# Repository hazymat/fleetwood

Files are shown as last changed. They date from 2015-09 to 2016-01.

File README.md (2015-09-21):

# fleetwood
Home Automation Room Controller

*** NOTE: Support for this project is not possible, however collaborators are warmly encouraged to contact me! ***

Project consists of:
- Arduino Sketch intended for Arduino Mega 2560
- Eagle files for 4 PC boards

1/ Sketch and Eagle schematics and board layouts are shared for information only.
2/ This project does not yet include an official BOM.

   Copyright 2015 Mat Smith

   Licensed under the Apache License, Version 2.0 (the "License");
   you may not use this file except in compliance with the License.
   You may obtain a copy of the License at

       http://www.apache.org/licenses/LICENSE-2.0

   Unless required by applicable law or agreed to in writing, software
   distributed under the License is distributed on an "AS IS" BASIS,
   WITHOUT WARRANTIES OR CONDITIONS OF ANY KIND, either express or implied.
   See the License for the specific language governing permissions and
   limitations under the License.

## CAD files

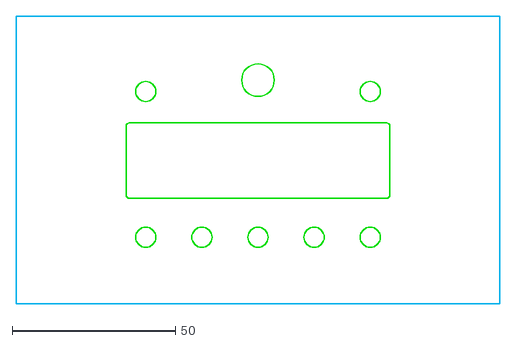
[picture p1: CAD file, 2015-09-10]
Eagle/Upper-Board/frontplate-with-outline-V4.dxf
148.1 x 88.1

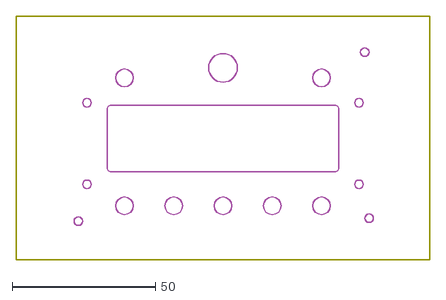
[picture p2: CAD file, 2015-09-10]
Eagle/Upper-Board/rearplate-with-outline-V4.dxf
144.3 x 85.0

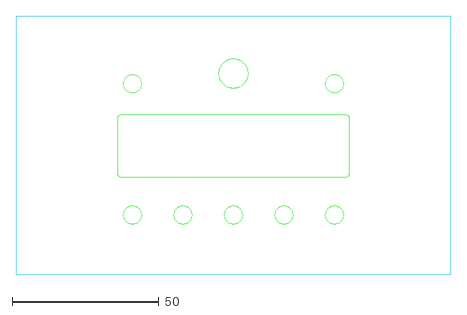
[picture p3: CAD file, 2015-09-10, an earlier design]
Eagle/Upper-Board/frontplate-with-outline-V2.dxf
148.1 x 88.1

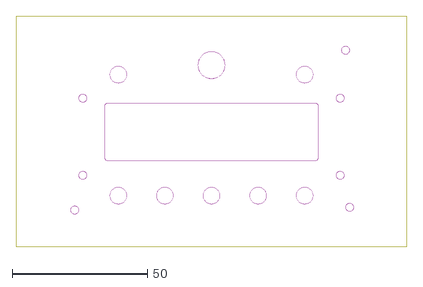
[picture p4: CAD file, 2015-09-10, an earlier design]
Eagle/Upper-Board/rearplate-with-outline-V3.dxf
144.3 x 85.0

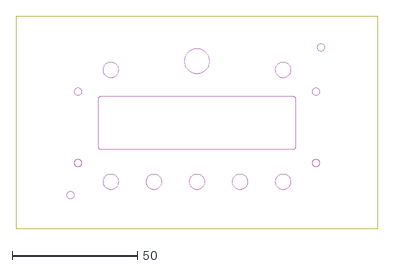
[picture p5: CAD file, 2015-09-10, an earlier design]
Eagle/Upper-Board/rearplate-with-outline-V2.dxf
144.3 x 85.0

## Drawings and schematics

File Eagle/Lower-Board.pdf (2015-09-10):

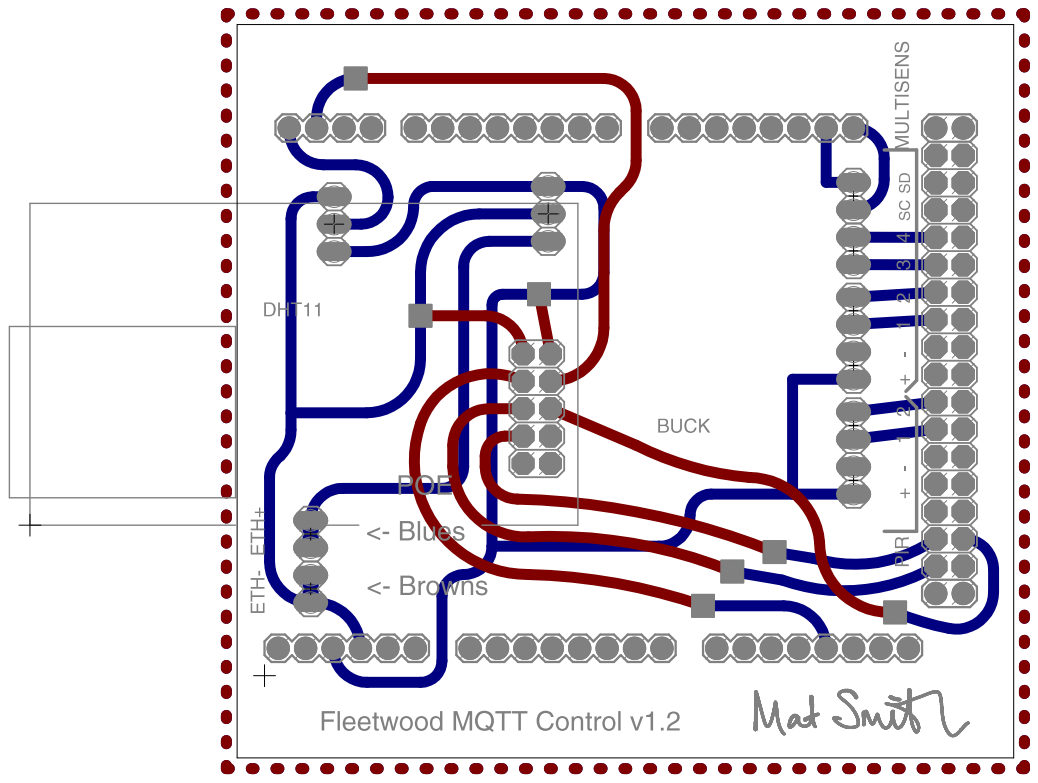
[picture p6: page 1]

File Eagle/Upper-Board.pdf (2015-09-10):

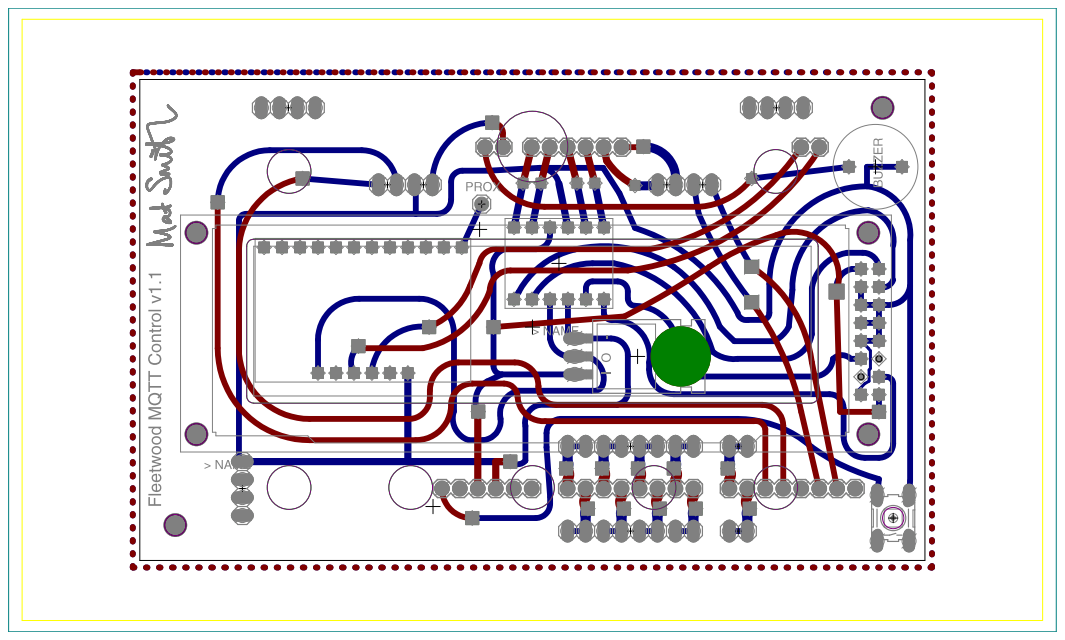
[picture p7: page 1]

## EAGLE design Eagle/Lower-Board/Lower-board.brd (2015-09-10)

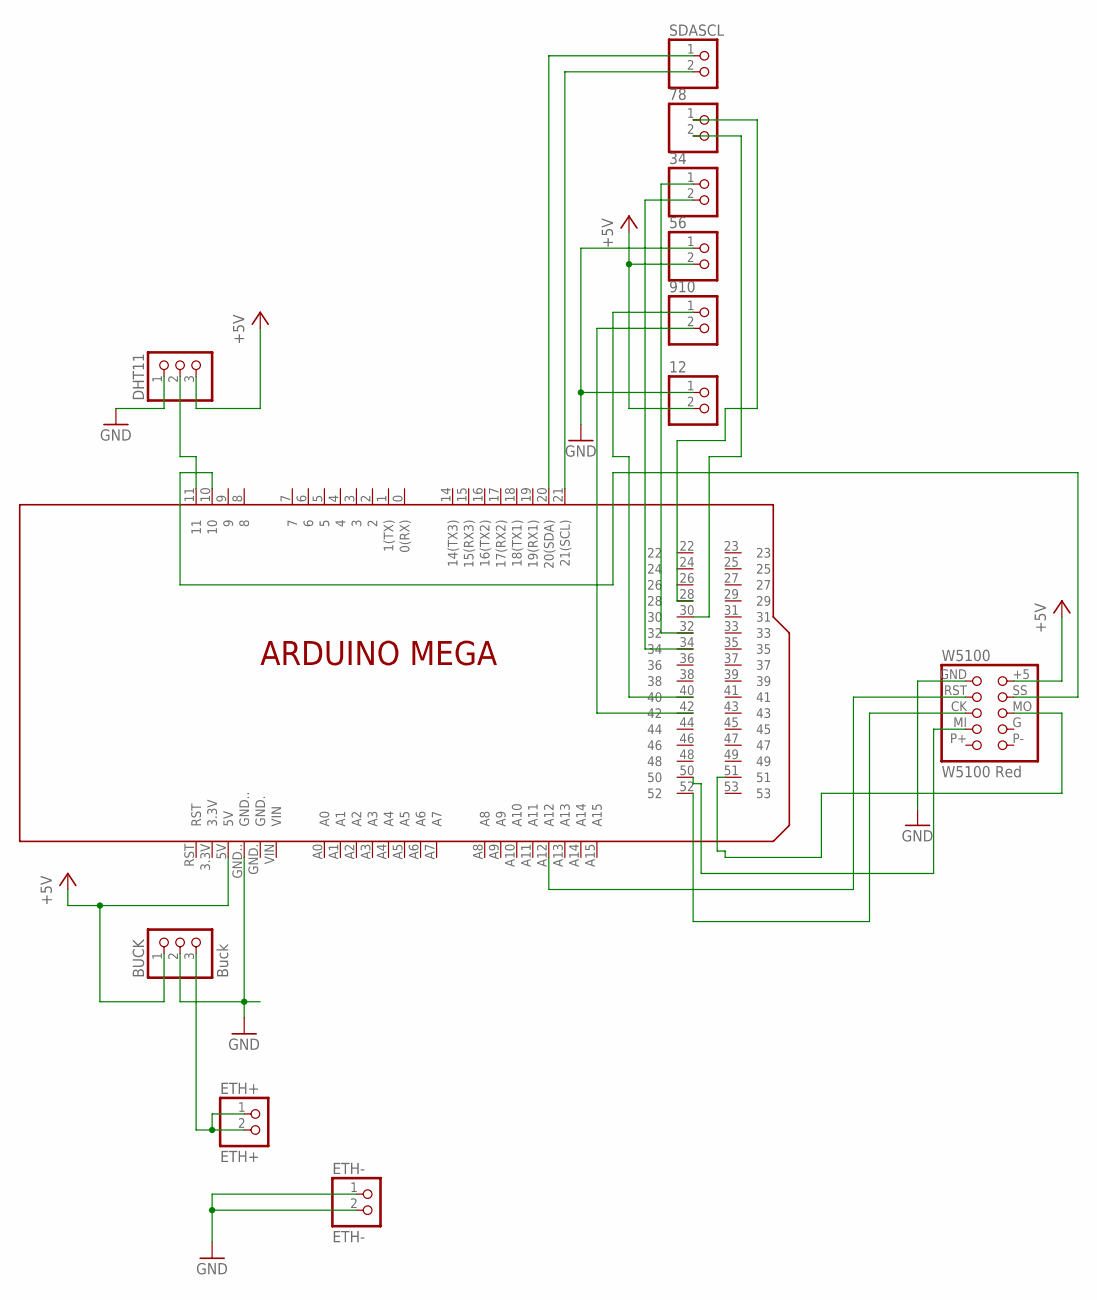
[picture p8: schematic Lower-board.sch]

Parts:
12, 34, 56, 78, 910: PINHD-1X2; 1X02
BUCK: Buck; 1X03
DHT11: PINHD-1X3; 1X03
ETH+: ETH+; 1X02
ETH-: ETH-; 1X02
SDASCL: PINHD-1X2; 1X02
U$1: ARDUINO_MEGA_1
W5100: W5100 Red; W5100-RED

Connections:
+5V: 12.2, 56.2, BUCK.1, DHT11.3, U$1.5V, W5100.+5
GND: 12.1, 56.1, BUCK.2, DHT11.1, ETH-.1, ETH-.2, U$1.GND.., W5100.GND
unnamed: BUCK.3, ETH+.1, ETH+.2
unnamed: SDASCL.2, U$1.21 (21(SCL))
unnamed: SDASCL.1, U$1.20 (20(SDA))
unnamed: DHT11.2, U$1.11
unnamed: 910.2, U$1.42
unnamed: 910.1, U$1.40
unnamed: 34.2, U$1.34
unnamed: 34.1, U$1.32
unnamed: 78.1, U$1.28
unnamed: 78.2, U$1.30
unnamed: U$1.52, W5100.CK
unnamed: U$1.50, W5100.MI
unnamed: U$1.A12, W5100.RST
unnamed: U$1.10, W5100.SS
unnamed: U$1.51, W5100.MO

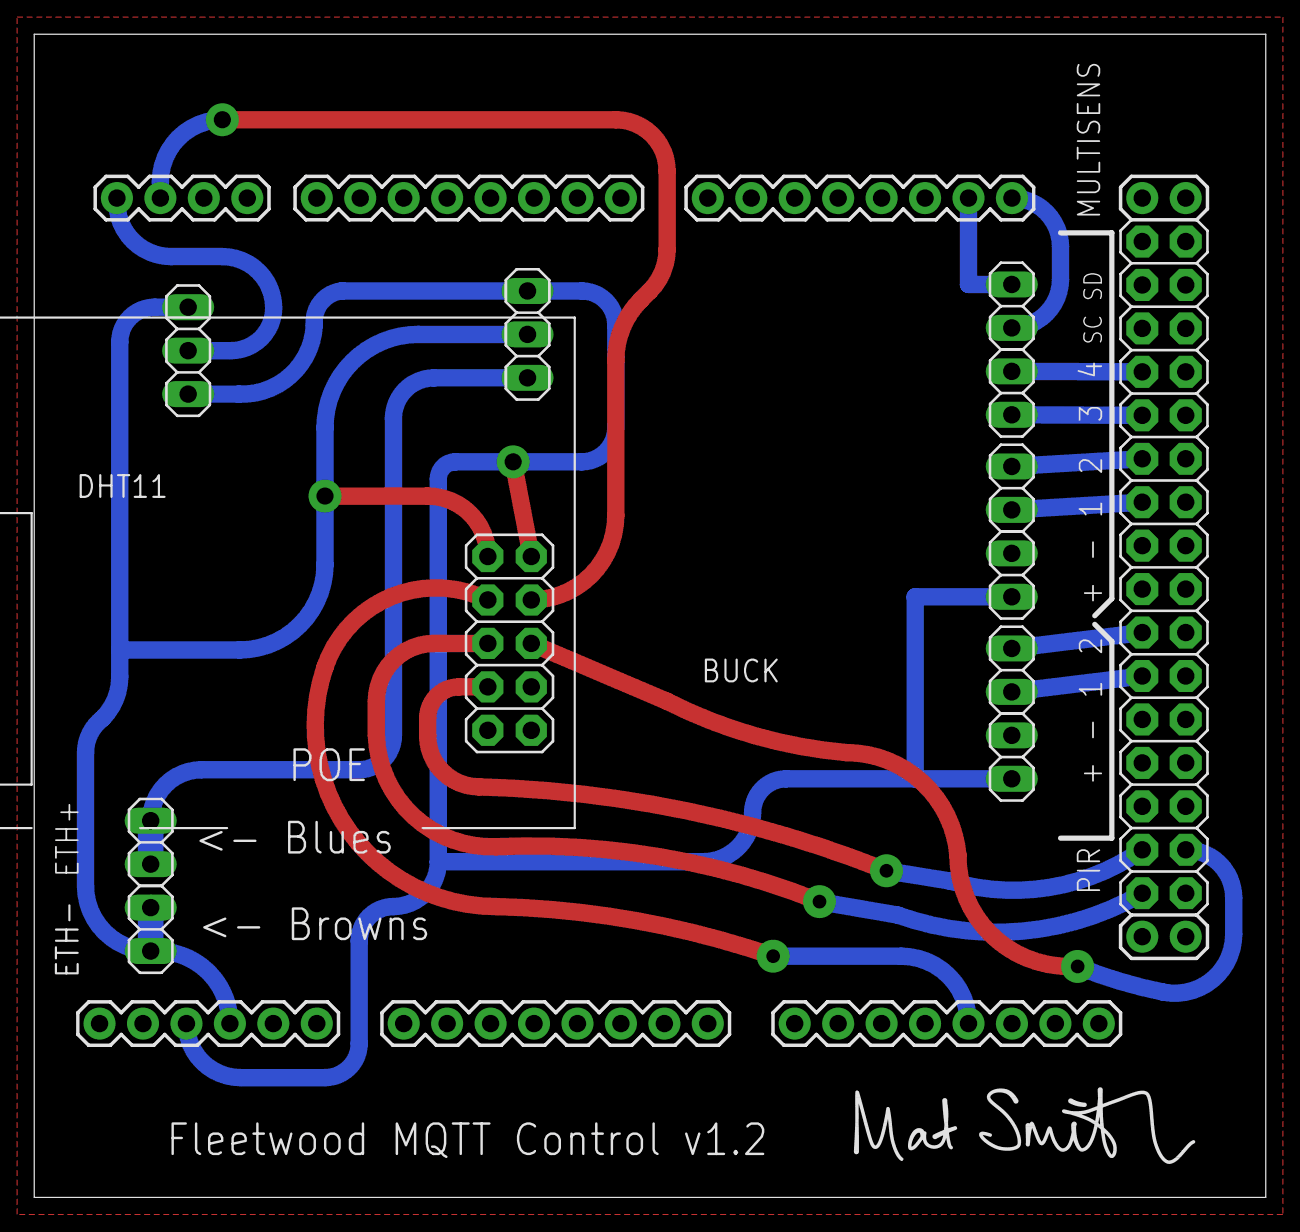
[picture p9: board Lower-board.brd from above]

Board: 2 copper layers, 72.0 x 68.0 mm, 12 parts (0 on the bottom side), 17 nets.

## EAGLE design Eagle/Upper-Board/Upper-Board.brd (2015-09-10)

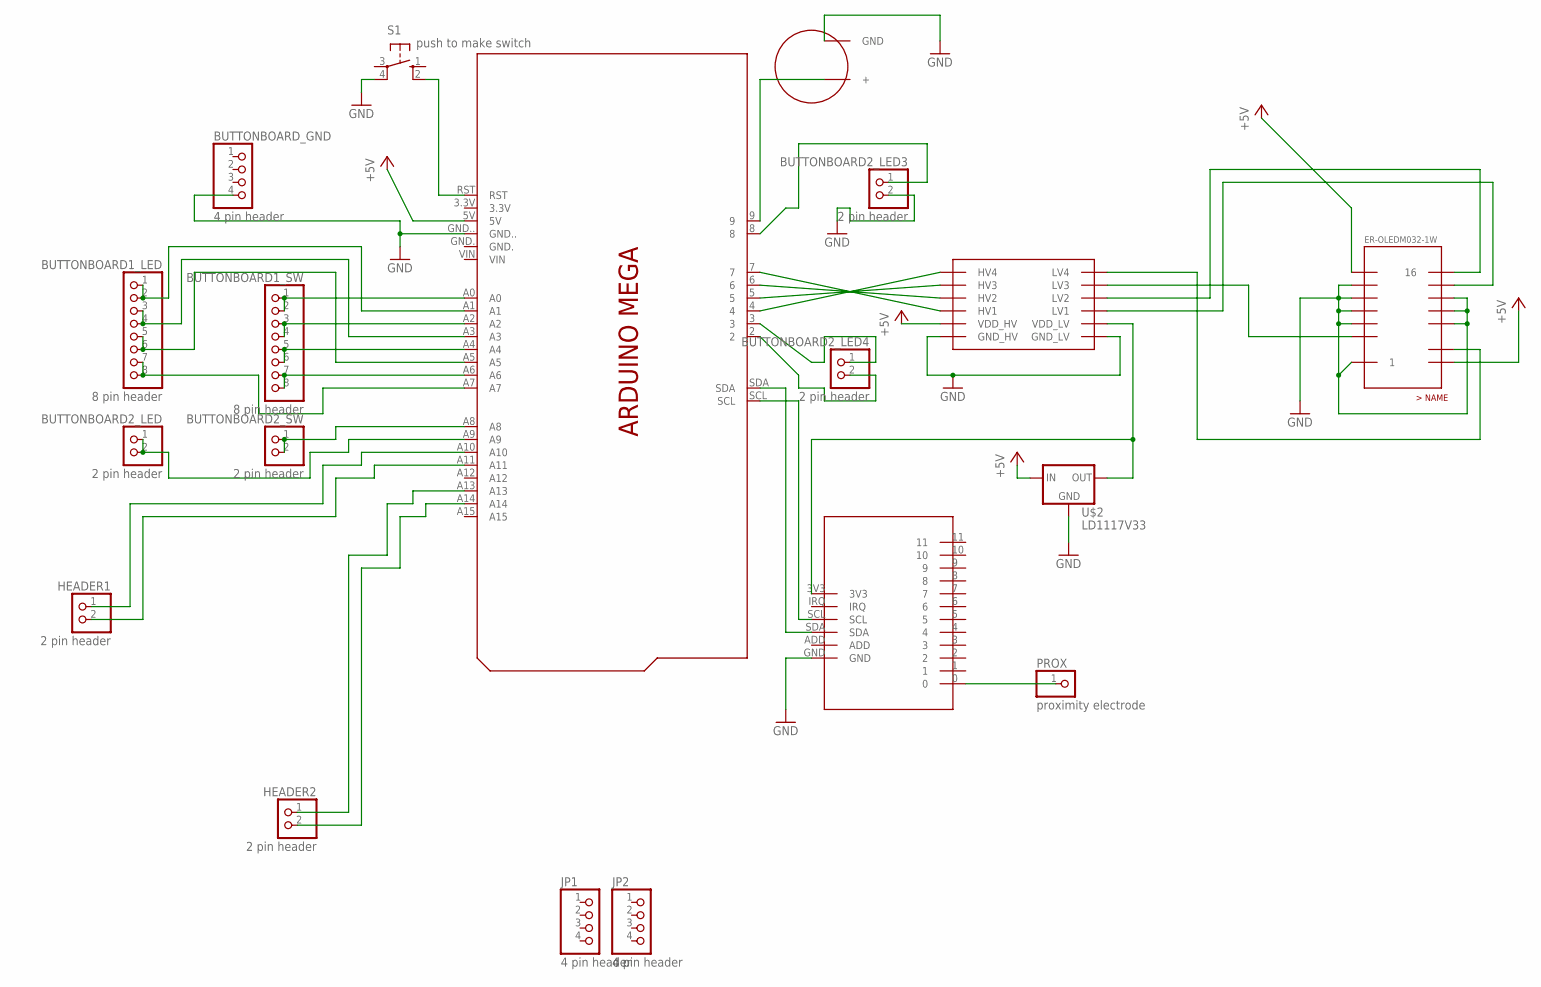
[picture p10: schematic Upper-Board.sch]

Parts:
BUTTONBOARD1_LED, BUTTONBOARD1_SW: 8 pin header; 1X08
BUTTONBOARD2_LED, BUTTONBOARD2_LED3, BUTTONBOARD2_LED4, BUTTONBOARD2_SW: 2 pin header; 1X02
BUTTONBOARD_GND: 4 pin header; 1X04
HEADER1, HEADER2: 2 pin header; 1X02
JP1, JP2: 4 pin header; 1X04
PROX: proximity electrode; 1X01
S1: push to make switch; B3F-10XX
U$1: ARDUINO_MEGA_2
U$2: LD1117V33
U$3: ER-OLED-M032-1W
U$4: BI_DIRECTIONAL_LEVEL_CONV
U$5: MPR121_BREAKOUT
U$6: BUZZER

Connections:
+5V: U$1.5V, U$2.IN, U$3.2, U$3.15, U$4.VDD_HV
GND: BUTTONBOARD2_LED3.2, BUTTONBOARD_GND.4, S1.4 (P1), U$1.GND.., U$2.GND, U$3.1, U$3.7, U$3.8, U$3.9, U$3.10, U$3.11, U$3.12, U$3.13, U$4.GND_HV, U$4.GND_LV, U$5.GND, U$6.GND
unnamed: BUTTONBOARD1_SW.1, BUTTONBOARD1_SW.2, U$1.A0
unnamed: BUTTONBOARD1_SW.3, BUTTONBOARD1_SW.4, U$1.A2
unnamed: BUTTONBOARD1_SW.5, BUTTONBOARD1_SW.6, U$1.A4
unnamed: BUTTONBOARD1_SW.7, BUTTONBOARD1_SW.8, U$1.A6
unnamed: BUTTONBOARD2_SW.1, BUTTONBOARD2_SW.2, U$1.A8
unnamed: BUTTONBOARD1_LED.1, BUTTONBOARD1_LED.2, U$1.A1
unnamed: U$1.SDA, U$5.SDA
unnamed: BUTTONBOARD1_LED.3, BUTTONBOARD1_LED.4, U$1.A3
unnamed: BUTTONBOARD1_LED.5, BUTTONBOARD1_LED.6, U$1.A5
unnamed: BUTTONBOARD1_LED.7, BUTTONBOARD1_LED.8, U$1.A7
unnamed: S1.2 (S1), U$1.RST
unnamed: BUTTONBOARD2_LED.1, BUTTONBOARD2_LED.2, U$1.A9
unnamed: U$1.SCL, U$5.SCL
unnamed: PROX.1, U$5.0
unnamed: U$1.9, U$6.+
unnamed: BUTTONBOARD2_LED3.1, U$1.8
unnamed: BUTTONBOARD2_LED4.1, U$1.3
unnamed: BUTTONBOARD2_LED4.2, U$1.2
unnamed: U$1.4, U$4.HV4
unnamed: U$1.5, U$4.HV3
unnamed: U$1.6, U$4.HV2
unnamed: U$1.7, U$4.HV1
unnamed: U$2.OUT, U$4.VDD_LV, U$5.3V3
unnamed: U$3.14, U$4.LV1
unnamed: U$3.16, U$4.LV2
unnamed: U$3.5, U$4.LV3
unnamed: U$3.4, U$4.LV4
unnamed: HEADER2.1, U$1.A13
unnamed: HEADER2.2, U$1.A14
unnamed: HEADER1.1, U$1.A10
unnamed: HEADER1.2, U$1.A11

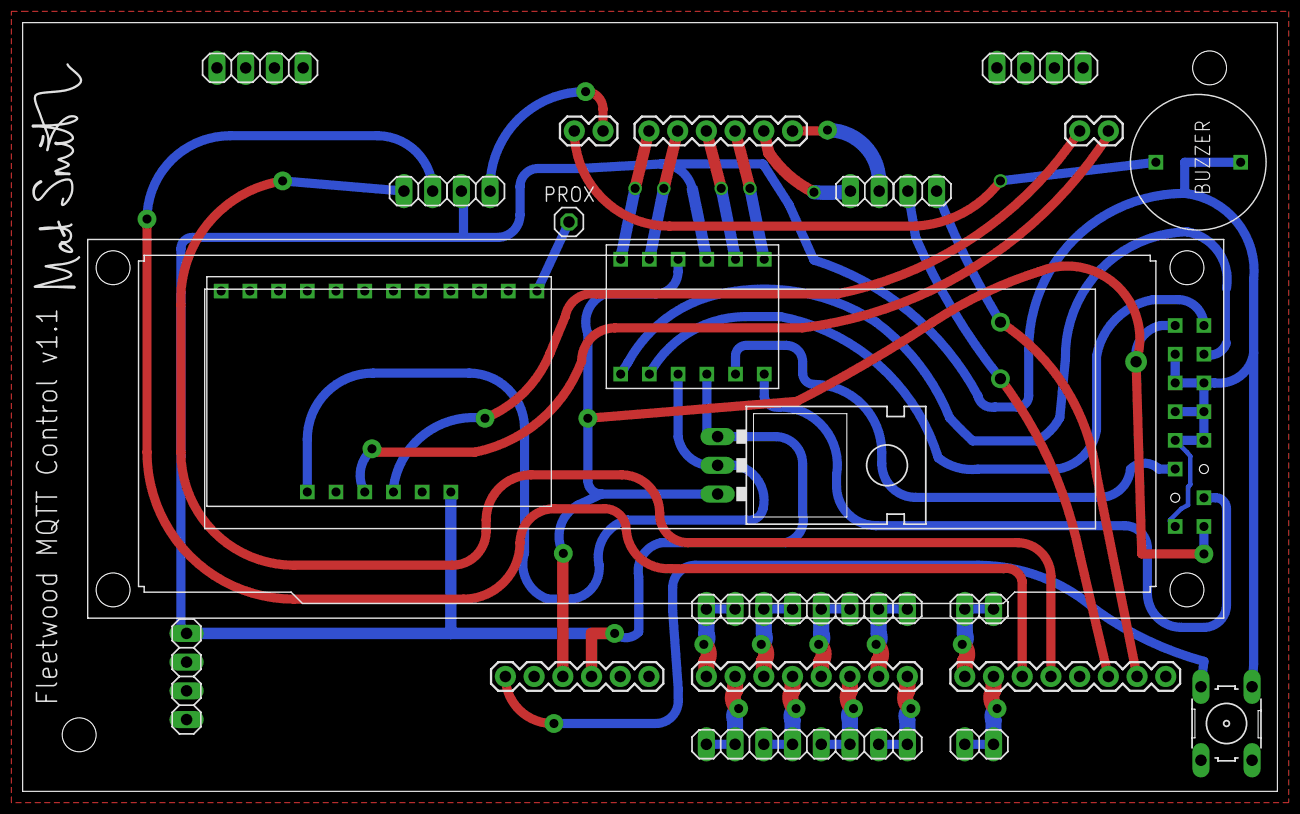
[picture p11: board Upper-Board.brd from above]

Board: 2 copper layers, 111.0 x 68.0 mm, 19 parts (0 on the bottom side), 33 nets.

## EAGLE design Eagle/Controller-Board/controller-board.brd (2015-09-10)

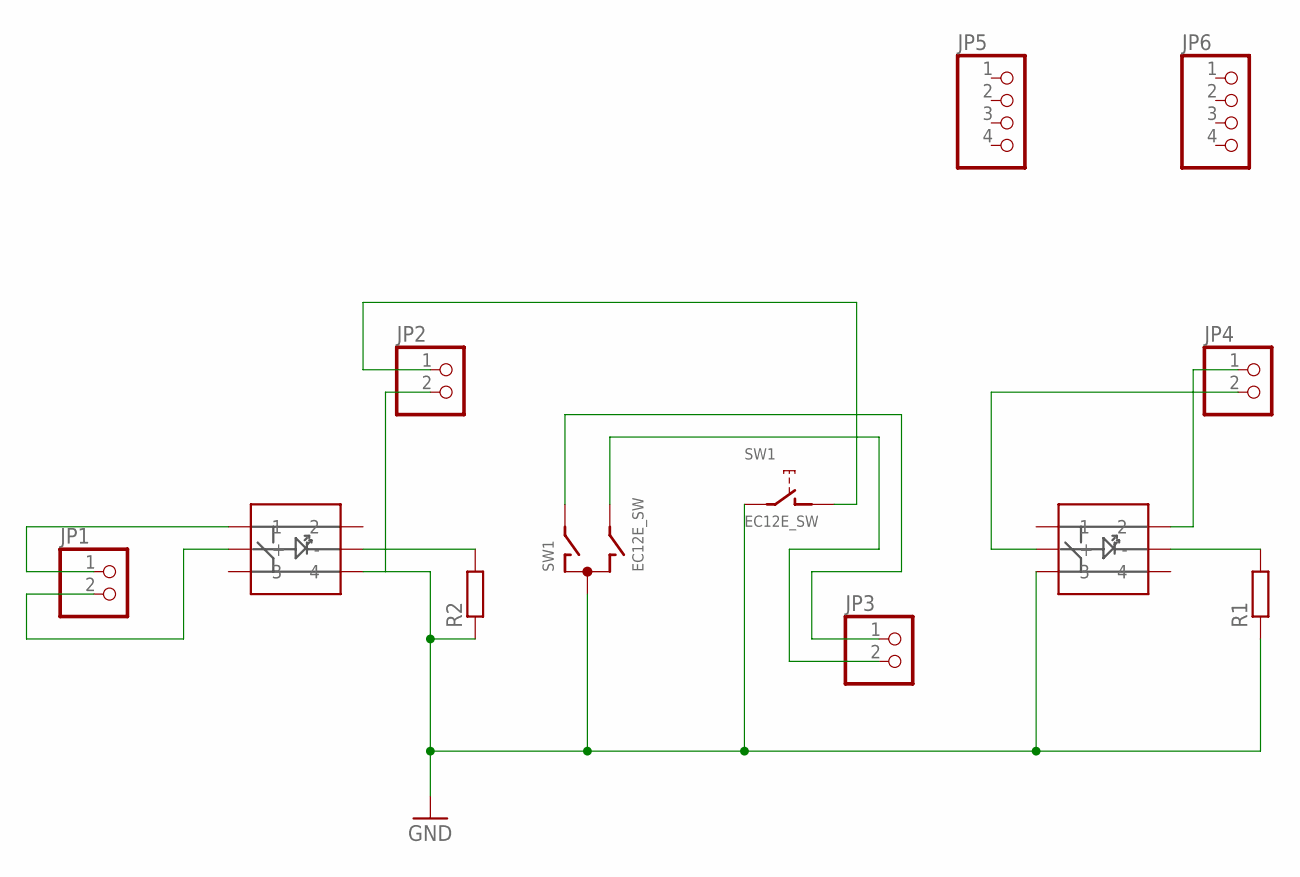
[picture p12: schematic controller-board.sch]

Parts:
BTN_MODE: PB614
BTN_OFF: PB614
JP1, JP2, JP3, JP4: PINHD-1X2; 1X02
JP5, JP6: PINHD-1X4; 1X04
R1, R2: R-EU_R1206; R1206
SW1: EC12E_SW; ALPS_EC12E_SW

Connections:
GND: BTN_MODE.4, BTN_OFF.3, JP2.2, R1.1, R2.1, SW1.C, SW1.E (2)
LED_MODE: BTN_MODE.L+ (+), JP1.2
unnamed: BTN_MODE.L- (-), R2.2
unnamed: BTN_OFF.L- (-), R1.2
unnamed: JP2.1, SW1.D (1)
unnamed: JP3.2, SW1.B
unnamed: JP3.1, SW1.A
unnamed: BTN_OFF.L+ (+), JP4.2
unnamed: BTN_OFF.2, JP4.1
SW_MODE: BTN_MODE.1, JP1.1

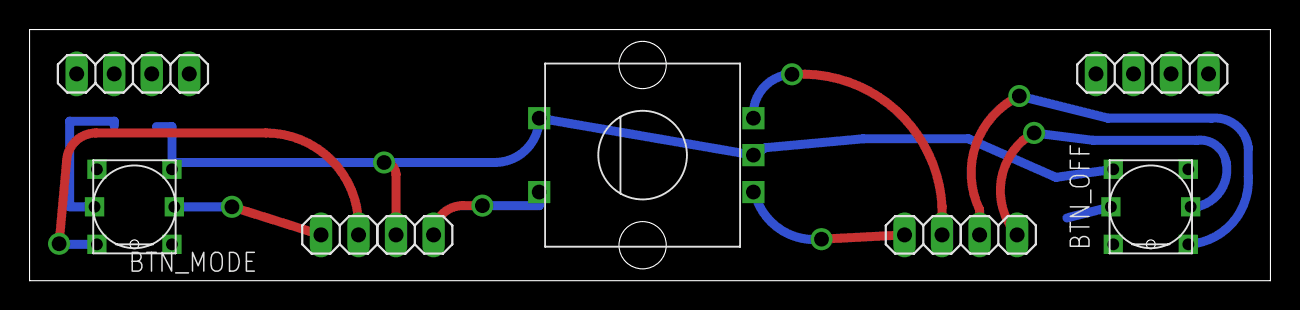
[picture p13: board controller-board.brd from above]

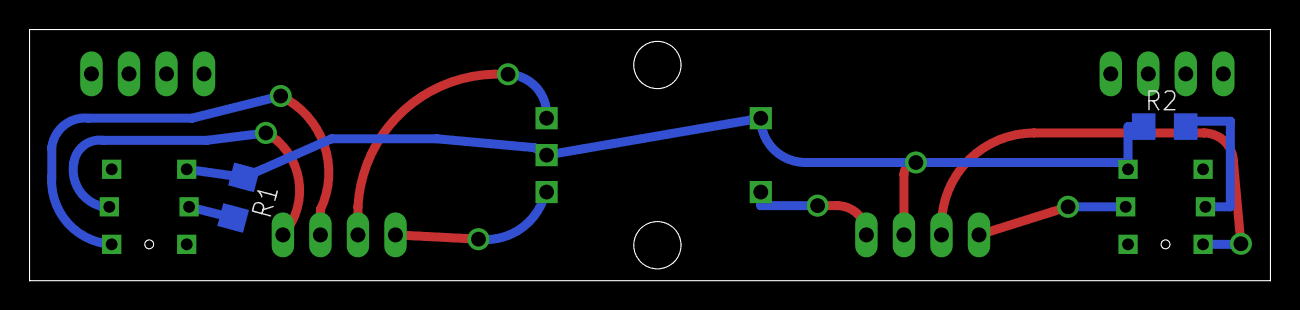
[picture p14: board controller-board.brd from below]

Board: 2 copper layers, 84.0 x 17.0 mm, 11 parts (2 on the bottom side), 10 nets.

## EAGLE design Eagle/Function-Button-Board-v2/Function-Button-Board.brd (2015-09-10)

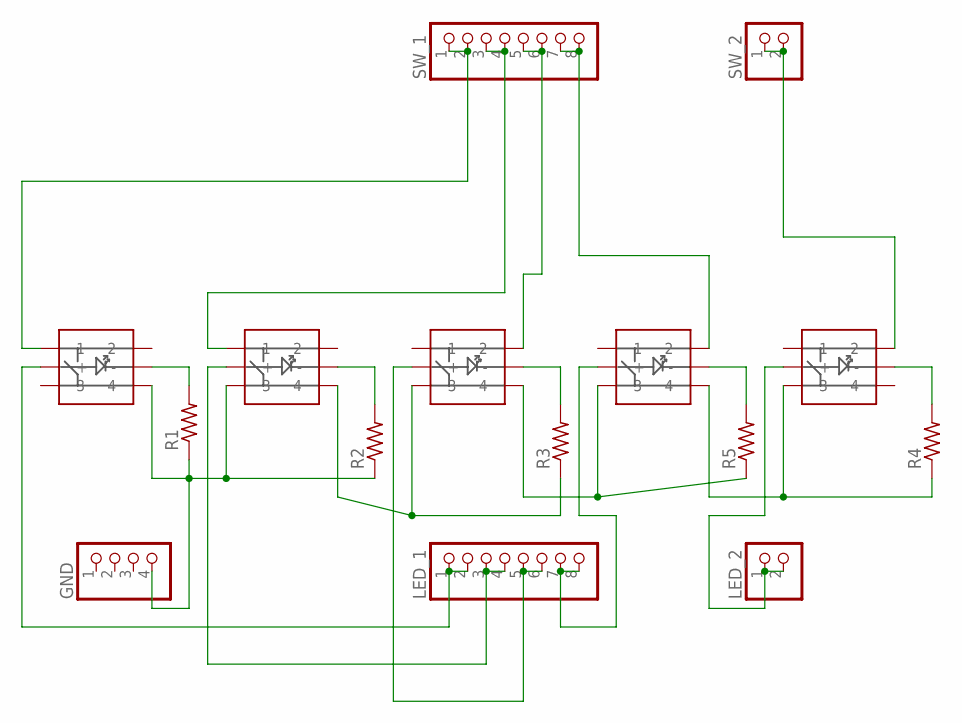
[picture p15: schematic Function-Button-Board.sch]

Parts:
FN_1, FN_2, FN_3, FN_4, FN_5: PB614
GND: PINHD-1X4; 1X04
LED_1: PINHD-1X8; 1X08
LED_2: PINHD-1X2; 1X02
R1, R2, R3, R4, R5: R-US_R1206; R1206
SW_1: PINHD-1X8; 1X08
SW_2: PINHD-1X2; 1X02

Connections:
unnamed: FN_1.L+ (+), LED_1.1, LED_1.2
unnamed: FN_1.L- (-), R1.2
unnamed: FN_1.1, SW_1.1, SW_1.2
unnamed: FN_3.L+ (+), LED_1.5, LED_1.6
unnamed: FN_1.4, FN_2.3, GND.4, R1.1, R2.1
unnamed: FN_4.L+ (+), LED_1.7, LED_1.8
unnamed: FN_2.1, SW_1.3, SW_1.4
unnamed: FN_2.L+ (+), LED_1.3, LED_1.4
unnamed: FN_5.L+ (+), LED_2.1, LED_2.2
unnamed: FN_2.L- (-), R2.2
unnamed: FN_3.L- (-), R3.2
unnamed: FN_2.4, FN_3.3, R3.1
unnamed: FN_4.L- (-), R5.2
unnamed: FN_5.L- (-), R4.2
unnamed: FN_3.2, SW_1.5, SW_1.6
unnamed: FN_3.4, FN_4.3, R5.1
unnamed: FN_5.2, SW_2.1, SW_2.2
unnamed: FN_4.2, SW_1.7, SW_1.8
unnamed: FN_4.4, FN_5.3, R4.1

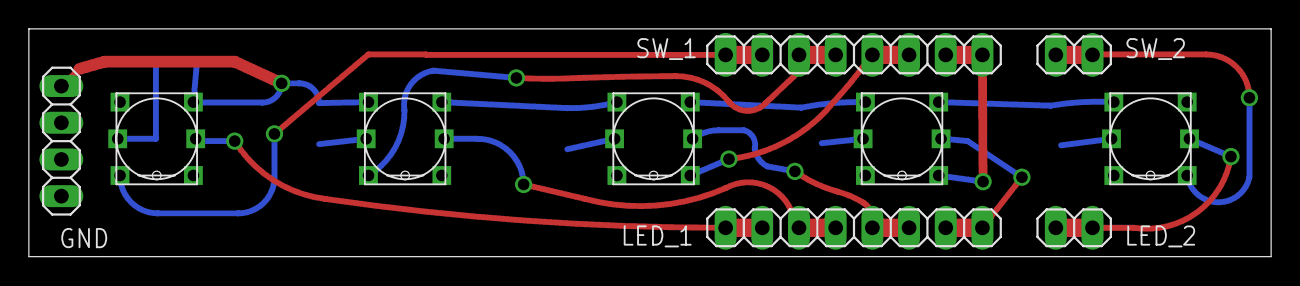
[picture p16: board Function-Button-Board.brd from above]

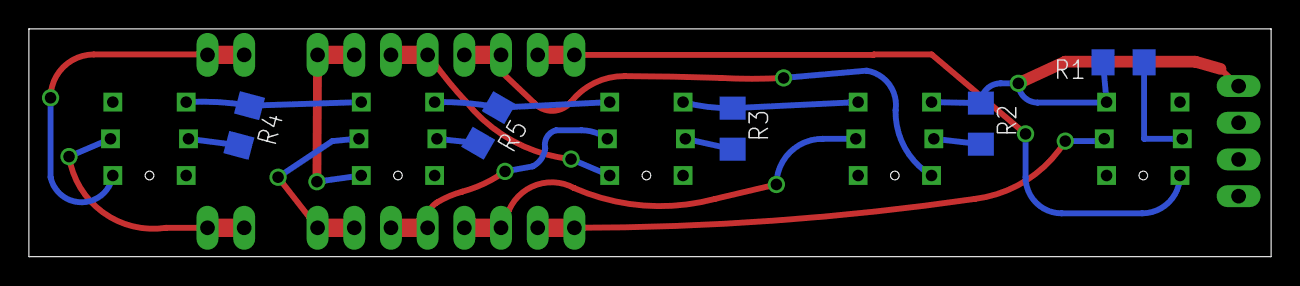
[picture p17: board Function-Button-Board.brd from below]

Board: 2 copper layers, 86.0 x 15.8 mm, 15 parts (5 on the bottom side), 19 nets.

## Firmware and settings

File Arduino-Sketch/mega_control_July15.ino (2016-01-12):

// 10/01/2016
/******************************************/
/*           Unit Settings                */
/******************************************/
// This unit's MAC address. MAC address is used for OpenHAB to recognise this controller at startup
// and give it the settings it should have, e.g. zone assignment, etc.
// i.e. zero config!
byte mac[] = {0xDE, 0xED, 0xBA, 0xFE, 0xFE, 0xED};  


/******************************************/
/*           Server settings              */
/******************************************/
// MQTT Server IP Address
byte server[] = {192, 168, 0, 21};

/******************************************/
/*           Display settings             */
/******************************************/
// Is the remote multisensor connected, i.e. do we wish to display lux setting?
#define showlightlevel 0

/******************************************/
/*           MQTT Topic Naming            */
/******************************************/
// MQTT topic naming. We are sending commands over MQTT topics like this:
//   rootvector/zonevector/commandvector
//   e.g. home/bedroom/arduinocommands
// ALL commands are sent on this one topic, however values received back over MQTT are
//   received over multiple topics.
// NB The zonevector is determined at startup by "downloading" this from OpenHAB over MQTT.
//   meaning that OpenHAB will determine the assigned zone given this unit's MAC address.
//   This makes it quick to deploy lots of units, as you'd only need to change the MAC above.
// None of the below really need changing! They are 'internal' names. Change only if you want different names for topics.
//   Topic paths are built from the below names.
#define rootvector "home"                          // do not exceed 10 chars, see below sram note
#define commandvector "megacmd"                    // do not exceed 10 chars, see below sram note
#define setupvector "megasetup"                    // do not exceed 10 chars
#define datetimevector "datetime/arduinodisplay"   // hmmm, think about #sram later. This seems ok
#define audiovector "audio"
#define titlevector "title"
#define artistvector "artist"
#define tempvector "temp"
#define boilervector "boiler"
#define weathervector "weath"
#define settempvector "settemp"
#define currentvector "current" // 
#define volumevector "volume" // 
#define playstatusvector "playstatus" // 
#define settingsvector "settings" // 
#define circuitcountvector "circuit_count" // 
#define circuit_1_namevector "circuit_1_name" // NB don't enter actual circuit names here. This is the vector used to obtain circuit names
#define circuit_2_namevector "circuit_2_name" // NB don't enter actual circuit names here. This is the vector used to obtain circuit names
#define circuit_3_namevector "circuit_3_name" // NB don't enter actual circuit names here. This is the vector used to obtain circuit names
#define circuit_4_namevector "circuit_4_name" // NB don't enter actual circuit names here. This is the vector used to obtain circuit names
#define circuit_5_namevector "circuit_5_name" // NB don't enter actual circuit names here. This is the vector used to obtain circuit names
#define circuit_6_namevector "circuit_6_name" // NB don't enter actual circuit names here. This is the vector used to obtain circuit names
#define light_scene_1_namevector "light_scene_1_name" // NB don't enter actual light scene names here...
#define light_scene_2_namevector "light_scene_2_name" // NB don't enter actual light scene names here...
#define light_scene_3_namevector "light_scene_3_name" // NB don't enter actual light scene names here...
#define light_scene_4_namevector "light_scene_4_name" // NB don't enter actual light scene names here...
#define light_scene_5_namevector "light_scene_5_name" // NB don't enter actual light scene names here...
#define audio_fave_1_namevector "audio_fave_1_name" // NB don't enter actual audio fave names here...
#define audio_fave_2_namevector "audio_fave_2_name" // NB don't enter actual audio fave names here...
#define audio_fave_3_namevector "audio_fave_3_name" // NB don't enter actual audio fave names here...
#define audio_fave_4_namevector "audio_fave_4_name" // NB don't enter actual audio fave names here...
#define audio_fave_5_namevector "audio_fave_5_name" // NB don't enter actual audio fave names here...
#define lightvector "light" //
#define circuit1levelvector "circuit1level" //
#define circuit2levelvector "circuit2level" //
#define circuit3levelvector "circuit3level" //
#define circuit4levelvector "circuit4level" //
#define circuit5levelvector "circuit5level" //
#define circuit6levelvector "circuit6level" //
#define heat_fave_1_namevector "heating_fave_1_name" // NB don't enter actual audio fave names here...
#define heat_fave_2_namevector "heating_fave_2_name" // NB don't enter actual audio fave names here...
#define heat_fave_3_namevector "heating_fave_3_name" // NB don't enter actual audio fave names here...
#define heat_fave_4_namevector "heating_fave_4_name" // NB don't enter actual audio fave names here...
#define heat_fave_5_namevector "heating_fave_5_name" // NB don't enter actual audio fave names here...


/******************************************/
/*          SRAM management note         */
/******************************************/
// I have hashtagged possible areas for improvement / troubleshooting regarding SRAM. So if we see
//   problems such as random text on screen then search for #sram.
// Most likely culprit would be buff[43]. To my calculations, assuming a topic root of
//   no more than 10 chars plus null terminator, buff[43] should be safe!
// Light circuit names, scene names, and audio favourites should be 11 chars max. This could be increased
//   by changing the struct 

/******************************************/
/*          Include libraries             */
/******************************************/

#include <ClickButton.h>
#include <Encoder.h>
#include <SPI.h>
#include <Ethernet.h>
#include <PubSubClient.h>
#include "U8glib.h"
#include "DHT.h" // DHT11/22 temp / humidity
#include <Wire.h>
#include <BH1750.h>            // #lux
#include "Adafruit_MPR121.h"   // #prox


/******************************************/
/*               Defines                  */
/******************************************/

// #sram memory management
// Maximum length for strings. This is the actual number of chars, we account for null terminator
//   on top of this. Keep this as LOW as poss.
#define nameLength 11      // Light circuit, scene, and audio fave names. (suggest 12)
#define trackLength 30     // Now Playing track: max length to accept / display onto Arduino. (suggest 60)
#define artistLength 32    // Now Playing artist: as above. (suggest 60)

// comment below line out if not debugging
#define DEBUG      // code step-through

// Pins
#define btn1Pin 		54	// illuminated tact switch - Switch part
#define led1Pin 		55	// illuminated tact switch - LED
#define btn2Pin 		56	// illuminated tact switch - Switch part
#define led2Pin 		57	// illuminated tact switch - LED
#define btn3Pin 		58	// illuminated tact switch - Switch part
#define led3Pin 		59	// illuminated tact switch - LED
#define btn4Pin 		60	// illuminated tact switch - Switch part
#define led4Pin 		61	// illuminated tact switch - LED
#define btn5Pin 		62	// illuminated tact switch - Switch part
#define led5Pin 		63	// illuminated tact switch - LED
#define btnMode 		64	// illuminated tact switch - Switch part
#define ledMode 		65	// illuminated tact switch - LED
#define btnAllOff               67
#define ledAllOff               68
#define encoder1 		3	// rotary encoder - right hand pin in row of 3 as you look down
#define encoder2 		2	// rotary encoder - left hand pin in row of 3 as you look down
#define encodersw 		8	// rotary encoder - switch part
#define oledClock		4	// OLED
#define oledData		5	// OLED
#define chipSelect		6	// OLED
#define commandDataSelect	7	// OLED
#define resetCtl                66      // don't ask. (separate w5100 reset)
#define ardReset                69      // hardwired to reset pin of Arduino - physical reset by MQTT
#define DHTPIN                  32      // was pin 11. With latest version of PCB, this is an external connector


//BREADBOARD:
/*
#define btnMode 		54	// illuminated tact switch - Switch part
#define ledMode 		55	// illuminated tact switch - LED
#define btn1Pin 		56	// illuminated tact switch - Switch part
#define led1Pin 		57	// illuminated tact switch - LED
#define btn2Pin 		58	// illuminated tact switch - Switch part
#define led2Pin 		59	// illuminated tact switch - LED
#define btn3Pin 		60	// illuminated tact switch - Switch part
#define led3Pin 		61	// illuminated tact switch - LED
#define btn4Pin 		62	// illuminated tact switch - Switch part
#define led4Pin 		63	// illuminated tact switch - LED
#define btn5Pin 		64	// illuminated tact switch - Switch part
#define led5Pin 		65	// illuminated tact switch - LED
#define encoder1 		2	// rotary encoder - right hand pin in row of 3 as you look down
#define encoder2 		3	// rotary encoder - left hand pin in row of 3 as you look down
#define encodersw 		8	// rotary encoder - switch part
#define oledClock		4	// OLED
#define oledData		5	// OLED
#define chipSelect		6	// OLED
#define commandDataSelect	7	// OLED
#define resetCtl                66      // don't ask. (separate w5100 reset)
#define ardReset                69      // hardwired to reset pin of Arduino - physical reset by MQTT
#define DHTPIN                  11      // DHT11 sensor (DHT22 is better, I had stock of the 11...)
*/

// Modes
#define lightMode 1
#define audioMode 2
#define tempMode 3
#define weatherMode 4
#define mvhrMode 5
#define otherMode 6
#define diagsMode 7
#define settingsMode 8

#define modeCount 7      // This is the number of modes to cycle through. There are other "hidden" modes, settings / diags.

// Proximity sense. We're calibrating this manually, using output from Serial Monitor to show us continuous values...
// Set baseline to lowest value you read from Serial Monitor (when no hand is near sensor)
// Set initial threshold to the number which, when capacitance goes below this number, the "touch" is sensed and controller wakes up etc.
// This initial threshold simply sets a value which can subsequently be overwritten by OpenHAB if we want to adjust this later
// 14/5/2015 - 656. Had to wait a good minute.

#define capBaseline 656                // Lowest value for Mat's wallplates is 670 #prox
#define capInitialThreshold 5          // Decent safety margin #prox

// Timeouts
#define w5100resetdelay 800            // Definitely safe: 1500. Probably ok 500?
#define startuphold 0                  // How long should we delay startup so allow us to view
                                       //   the final page of status messages? (set to 0 for now as added big delays to settings request routine)
                                       //   ... i.e. no point in delaying even more at startup
#define button_leds_off_timeout 5000
#define default_mode_timeout 913500
#define display_dim_timeout 97000
#define display_off_timeout 919000
#define heartbeat_timeout 61000 // we expect an MQTT message at least every 60 seconds
#define initialmqttconnecttimeout 5000 // should be 35000
#define preset_stored_msg_timeout 1500


// Delay between requesting each setting / value over MQTT to allow OH to process
// On this front, Arduino is really reliable with fast processing of MQTT, OpenHAB is not so!
#define mqttsettingsreqdelay 400
#define mqttvalreqdelay 400

#define DHTTYPE DHT22   // DHT 22
#define dhtpolldelay 20000    // Take reading and send every e.g. 20 seconds
#define lightSensorDelay 1000 // #lux
#define scrollwait 1000 // time to wait before scrolling text

/******************************************/
/*            Define settings             */
/******************************************/

// #sram memory hungry this struct is! mainly because of the char text[30]
struct serverData
{
  char name[nameLength+1];    // for storing a name of the server setting (e.g. "Ceiling")
  int level;                  // for storing a numerical value for the setting if applicable (e.g. 30)
//  char text[30];            // for storing a text value for the setting if applicable (e.g. audio track name)
  int gotName;                // (e.g. if the name was downloaded successfully, this is set to 1)
  int gotLevel;               // (e.g. if a settingTextVal OR settingNumberVal was downloaded successfully, this is set to 1)
};

struct weather {
  char name[nameLength+1];
  char min[4];
  char max[4];
  char precip[4];
  char conditiontext[25];
  char humid[4];
};

typedef struct serverData ServerData;
typedef struct weather Weather;

Weather weatherDay[5];

ServerData lightCircuit[6];  // store circuit names and light levels for 6 light circuits in a room
ServerData lightScene[5];
ServerData audioFave[5];
ServerData heatingProfile[5];

// server values
boolean play_status;
char track[trackLength+1];
char artist[artistLength+1];
char serverdatetime[17];
int temp; // #sram We aren't this desperate, but if we were, this could be stored as a char or byte
int volume; // #sram
int temp_target; // #sram
int mvhr_speed; // #sram
char zonename[15] = {'<','d','e','f','a','u','l','t','>','\0'};        // Zone name (14 chars max to be received from OpenHAB)
char zonevect[15] = {'<','d','e','f','a','u','l','t','>','\0'};        // Zone vector (14 chars max to be received from OpenHAB)
char zonepmsg[30] = {' ','\0'};        // Zone pager message (29 chars max to be received from OpenHAB)
int capThreshAdjust = capInitialThreshold;     // Zone controller proximity sense adjustment
int lowestCapVal = 9999;  // initialise with high number
boolean boiler_status;

// settings
int circuitCount = 6; // This is the initial circuit count number. This is overwritten when Arduino receives setting from OpenHAB
                      //  set to 6 so that we catch all circuit values in the case where values arrive before the setting itself
                      //  If we see circuit value of -1, this means we think there is a circuit but haven't got the value yet
char commandtopic[41]; // array size: topicroot/zonevector/commandvector (max 11 + 15 + 11 respectively, plus 2x "/" strings)

// OPTIMISE THIS
char buff[43]; // general buffer. char array. Assuming topicroot is max 10 chars with null terminator
               // this should not ever exceed 43. #sram
char ipString[16];  // char array for displaying the IP address at startup (and any other time, diagnostics?)
char macString[13]; // 12 digit MAC address displayed at startup plus null terminator...
char *modeText[] = {"LIGHT", "AUDIO", "TEMP", "WEATHER", "MVHR", "OTHER", "DIAG", "SETTING"}; // #sram

char* settingsNames[] = {"Download", "Slow downld", "Diags", "Reboot", "Exit"}; //#sram

/******************************************/
/*         Define global vars             */
/******************************************/
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
void loop()
{
  u8g.firstPage();  // START U8G
  do {              // START U8G
  drawControl();  // START U8G

  /******************************************/
  /*        touch sensor #prox              */
  /******************************************/

  // Get the currently touched pads
  currtouched = cap.touched();
  if (currtouched) defaultmodetimer = millis();
  for (uint8_t i=0; i<12; i++) {
    // it if *is* touched and *wasnt* touched before, alert!
    if ((currtouched & _BV(i)) && !(lasttouched & _BV(i)) ) {
      // Serial.print(i); Serial.println(" touched");
    }
    // if it *was* touched and now *isnt*, alert!
    if (!(currtouched & _BV(i)) && (lasttouched & _BV(i)) ) {
      // Serial.print(i); Serial.println(" released");
    }
  }
  // reset our state
  lasttouched = currtouched;

  /******************************************/
  /*        Take Light Readings             */
  /******************************************/
  if (millis() - lightSensorCounter > lightSensorDelay) {
    lux = lightMeter.readLightLevel();
    // Serial.print("Light: ");
    // Serial.print(lux);
    // Serial.println(" lx");
    lightSensorCounter = millis();
  }

  /******************************************/
  /*        Get values from server          */
  /******************************************/

  // If values are yet to be downloaded
  // e.g. if they have never been downloaded, or if they need to be downloaded again
  if (gotinfofromserver == false) {
    requestSettingsFromServer();
    requestValuesFromServer();
    // Insert code here to check if all settings / vals downloaded from server, if so...
    gotinfofromserver=true;
  }
  
  /******************************************/
  /*        Take DHT Readings               */
  /******************************************/
  if (millis() - dhtpollcounter > dhtpolldelay) {
//    float h = dht.readHumidity();
//    float t = dht.readTemperature();
//    float f = dht.readTemperature(true);
//    if (isnan(h) || isnan(t) || isnan(f)) {
//      Serial.println("Failed to read from DHT sensor!");
//      return;
//    }
//    float hi = dht.computeHeatIndex(f, h);
    dtostrf(dht.readTemperature(), 4, 1, buff);  //4 is mininum width, 3 is precision; float value is copied onto buff
    client.publish("home/bedroom/megacmd/temp", buff);
    dhtpollcounter = millis();
  }

  /******************************************/
  /*  Dim display, lights, sleep mode etc.  */
  /*  This needs a bit of tidying, was lazy */
  /******************************************/
    
    u8g.setFont(u8g_font_helvB12); // set font, for the purposes of working out what the width of the track text is
    int overflowamount = u8g.getStrWidth(track) - 256 - major_text_x_coord;

    if (u8g.getStrWidth(track) > 256 - major_text_x_coord) {
      if (millis() - scrollTimer > scrollwait) { // start to do the scroll after waiting
        if (titleoffset > overflowamount - 150) {
          titleoffset--;
        } else {
          scrollTimer = millis();
          titleoffset = 0;
        }
      }
    }
    
    if (millis() - defaultmodetimer > button_leds_off_timeout) { // Dim the lights
      turnLEDs(0);
    } else {
      turnLEDs(1);
    }
    if (currentMode == diagsMode) {
      turnLEDs(1);
    }

    if (millis() - defaultmodetimer > display_dim_timeout) { // Dim the lights
      u8g.setColorIndex(1);         // min intensity
    } else {
      u8g.setColorIndex(3);         // max intensity
    }

  if (millis() - defaultmodetimer > default_mode_timeout) { // Default back to light control mode
      if (currentMode == diagsMode) {
        // Do nothing - stay in this mode forever
      }
      else if (currentMode != 1) {
        currentMode = 1;
      }
      if (currentCircuit != 1) {
        currentCircuit = 1;
      }
    }
    
  /******************************************/
  /*       Respond to button inputs         */
  /******************************************/
  btnSelect.Update();
  btnOrf.Update();
  btnTransport.Update();
  btnF1.Update();
  btnF2.Update();
  btnF3.Update();
  btnF4.Update();
  btnF5.Update();
  if (btnSelect.clicks == 1) buttonFunc ("cyclemodes");        // Cycle through modes
  if (btnTransport.clicks == 1) buttonFunc ("rotarySingle");   // Press rotary 
  if (btnTransport.clicks == 2) buttonFunc ("rotaryDouble");   // Double press rotary
  if (btnTransport.clicks == 3) buttonFunc ("rotaryTriple");   // Triple press rotary
  if (btnF1.clicks == 1) buttonFunc ("Button1");               // Press Favourite button 1
  if (btnF1.clicks == -1) buttonFunc ("Store1");               // Store Favourite 1
  if (btnF1.clicks == 2) buttonFunc ("enterSettings");            // Double press Fave 2 button to download from server again
  if (btnF2.clicks == 1) buttonFunc ("Button2");               // Press Favourite button 2
  if (btnF2.clicks == -1) buttonFunc ("Store2");               // Press Favourite button 2
  if (btnF3.clicks == 1) buttonFunc ("Button3");               // Press Favourite button 3
  if (btnF3.clicks == -1) buttonFunc ("Store3");               // Press Favourite button 3
  if (btnF4.clicks == 1) buttonFunc ("Button4");               // Press Favourite button 4
  if (btnF4.clicks == -1) buttonFunc ("Store4");               // Press Favourite button 4
  if (btnF5.clicks == 1) buttonFunc ("Button5");               // Press Favourite button 5
  if (btnF5.clicks == -1) buttonFunc ("Store5");               // Press Favourite button 5
  if (btnOrf.clicks == 1) buttonFunc ("Orf");                  // Press Favourite button 5

  /******************************************/
  /*       Respond to encoder inputs        */
  /******************************************/
  int newPosition = myEnc.read();
  if (newPosition > oldPosition) {
    oldPosition = newPosition;
    rotaryFunc("up");
    // Serial.println("Up");
  }
  else if (newPosition < oldPosition) {
    oldPosition = newPosition;
    rotaryFunc("down");
    // Serial.println("Down");
  }
  client.loop();
  } // END U8G
  while( u8g.nextPage() ); // END U8G
} // end of loop


/******************************************/
/*       Supporting Functions             */
/******************************************/
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

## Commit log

2015-09-10 Addition of project code
    [Function-Button-Board.GBL, Function-Button-Board.GBO, Function-Button-Board.GBP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]
2015-09-10 Addition of board PDFs and tidy
    [Function-Button-Board.GBL, Function-Button-Board.GBO, Function-Button-Board.GBP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]
2015-09-10 Addition of board layout PDFs
    [Function-Button-Board.GBL, Function-Button-Board.GBO, Function-Button-Board.GBP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]
2016-01-11 - implemented heating mode with boiler status, current and set temp, and heating presets - started to move display text into u8g program memory: SRAM improvements - new weather mode and weather icon
